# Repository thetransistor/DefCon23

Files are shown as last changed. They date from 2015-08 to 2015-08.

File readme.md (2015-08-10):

# DC801 2015 Defcon VIP Party Badge
[DC801](https://dc801.org/) and [theTransistor](http://thetransistor.com/) bring you yet another fun party badge.

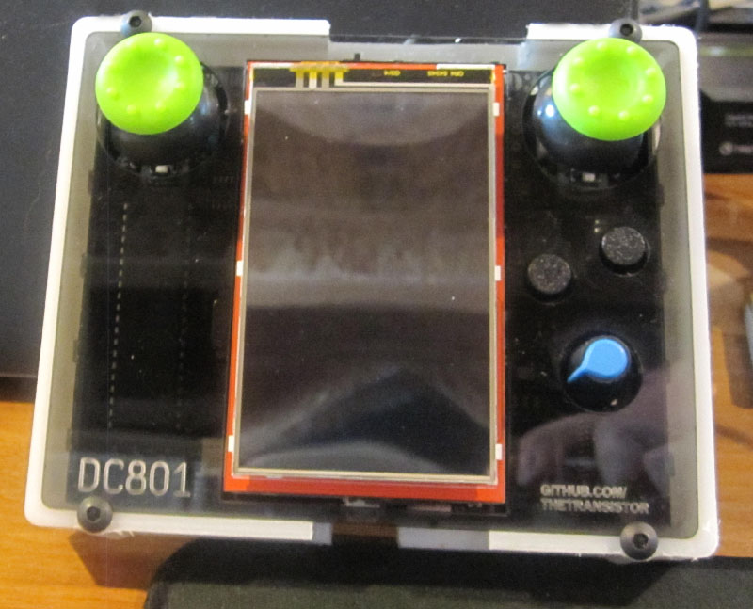
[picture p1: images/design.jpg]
Defcon VIP Party Badge 2015


##Features
- [Parallax Propeller mCU](https://www.parallax.com/product/p8x32a-d40)
- Atmega328P mCU (For analog and additional IO)
- ESP8266 (ESP-12E) WiFi Module
- Socket for XBee Serial Radio
- FTDI with Selectable Output via Bus Switch
- 3.6" LCD
  - 400x240 Resolution
  - 18-bit Color
  - ~~ILI9327~~ R61509V Chipset
- 2000 mAh LiPo Battery and Charging Circuit
- Awesome HDPE / Acrylic Case
- 2x Analog Joysticks
- Rotary Encoder
- 2x Pushbuttons
- 10x WS2812B RGB LED Pixels
- Charge / Voltage Readout Capabilities
- microSD Card

##Credits:

**Electronics Engineering**
- Compukidmike

**Original Design**
- D3c4f

**Case Manufacturing**
- [Isaac @ Rusted Friend](http://rustedfriend.com/)

**QA, Assembly, Software, Loading, Misc**
- @d3c4f
- @compukidmike
- @animcogn
- @aarobc (l3mur)
- @doktorunicorn
- @programm3rq
- @mindjuju
- @devil_bunny (yukaia)
- @nemus801
- SausageAssassn 

**Special Thanks**
- All you amazing hackers that help fund this project every year! <3
- DC801 and theTransistor Crews
- Utah Open Source

##Questions and Comments
Questions and comments can be directed towards the following forms of communication:
- #thetransistor on freenode
- d3c4f [at] thetransistor [dot] com

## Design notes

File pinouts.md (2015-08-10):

# DC801 2015 Pinout
Pinouts for the DC801 Electronic VIP Party Badge for Defcon 2015 for kids who can't read good and wanna learn to do other stuff good too

##Propeller IO Pinout
Propeller IO | LCD Pin
-------------|--------------
P0  | D2
P1  | D3
P2  | D4
P3  | D5
P4  | D6
P5  | D7
P6  | D0
P7  | D1
P11 | RST
P12 | CS
P13 | RS
P14 | RW
P15 | RD

Propeller IO | SD Card
-------------|--------------
P20 | SCK
P21 | DO
P22 | DI
P23 | SS

Propeller IO | RGB LEDS
-------------|--------------
P26 | Data

Propeller IO | XBee Socket
-------------|--------------
P8  | DOUT
P9  | DIN
P10 | RST

Propeller IO | WiFi
-------------|--------------
P24 | RX
P25 | TX
P27 | RST

Propeller IO | EEPROM
-------------|--------------
P28 | SCL
P29 | SDA

Propeller IO | PROP Serial
-------------|--------------
P30 | TX
P31 | RX

Propeller IO | Atmega 328P Arduino
-------------|--------------
P16 | D13 (SCK)
P17 | D12 (MISO)
P18 | D11 (MOSI)
P19 | D10 (CS)

##Atmega328P IO Pinout
328P | Arduino IO | Rotary Encoder
-----|------------|--------------
32 | D2 | Encoder 1
1  | D3 | Encoder 2

328P | Arduino IO | Buttons
-----|------------|--------------
2  | D4 | Button A
9  | D5 | Button B
10 | D6 | RightJoy Button
11 | D7 | LeftJoy Button

328P | Arduino IO | Joystick 
-----|------------|--------------
23 | A0 | LeftJoy X-Axis
24 | A1 | LeftJoy Y-Axis
25 | A2 | RightJoy X-Axis
26 | A3 | RightJoy Y-Axis

328P | Arduino IO | Propeller Link
-----|------------|--------------
14 | D10 | P19 (CS)
15 | D11 | P18 (MOSI)
16 | D12 | P17 (MISO)
17 | D13 | P16 (SCK)

328P | Arduino IO | Misc
-----|------------|--------------
27 | A4 | LCD Backlight Control
12 | D8 | Battery Stat 1
13 | D9 | Battery Stat 2
22 | A7 | Battery Voltage
30 | RX | Arduino RX
31 | TX | Arduino TX

328P | Arduino IO | Extra IO
-----|------------|--------------
19 | A6 | Extra IO 1
28 | A5 | Extra IO 2

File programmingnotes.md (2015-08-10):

# Programming notes
[DC801](https://dc801.org/) and [theTransistor](http://thetransistor.com/) bring you yet another fun party badge.

##Progamming the Propeller
- [Parallax Propeller mCU](https://www.parallax.com/product/p8x32a-d40)
- 1) Plug in your USB and slide the bottom switch to the left to select the Propeller Chip
- 2) Use your favorite Propeller Tool to program the chip.
NOTE: Make sure you have selected "RTS" as the Propeller Reset Signal (see image below)
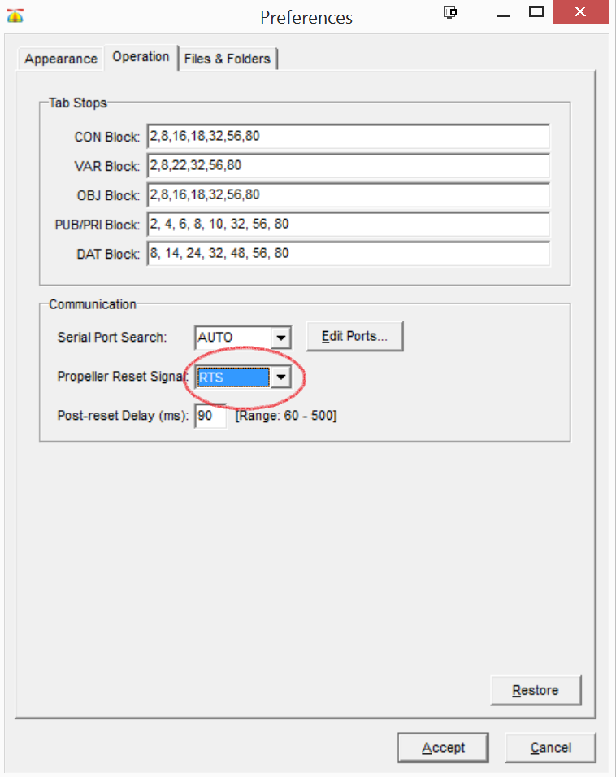
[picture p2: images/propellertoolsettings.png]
Defcon VIP Party Badge 2015


##Programing the Atmega328 Arduino
The Atmel 328P comes preloaded with the Arduino Bootloader. It sets up an SPI communication link between some of the IO (like the analog sticks) and the Propeller.
- 1) Plug in your USB and slide the bottom switch to the right to select the 328P
- 2) Use your favorite Arduino Programming Tool to program the chip.

##Flashing the Arduino Bootloader / Direct Atmel Programming
This is a little more advanced, and requires you to remove the Propeller chip from its socket. Please review the schematics if you wish to program the 329P directly.

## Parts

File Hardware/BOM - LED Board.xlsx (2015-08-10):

DC801 DEFCON23 Badge LED Board 2015
Qty | Value | Device | Package | Description
5 |  | WS2812B | WS2812B | WS2812B - Intelligent control LED integrated light source
5 | 0.1uF | C-USC0603 | C0603 | CAPACITOR, American symbol

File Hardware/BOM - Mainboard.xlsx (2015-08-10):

DC801 DEFCON23 Badge BOM 2015
Qty | Value | Device | Package | Description
1 |  | ENCODER-QUADRATURE | ENCODER-12MM-VERT | quadrature encoder EVE-GA1F2024B
1 | 1uH | INDUCTOR0805 | 805 | Inductors
1 |  | JST_2MM_MALE | JST-2-SMD | Mates to single-cell LiPo batteries.
1 | RED | LED0603 | LED-0603 | LED RED
3 | GRN | LED0603 | LED-0603 | LED GREEN
4 | 0.1uF | C-USC0805 | C0805 | CAPACITOR, American symbol
12 | 10K | R-US_R0603 | R0603 | RESISTOR, American symbol
1 | 10R | R-US_R0603 | R0603 | RESISTOR, American symbol
1 | 10uF | C-USC1206K | C1206K | CAPACITOR, American symbol
2 | 1uF | C-USC1206K | C1206K | CAPACITOR, American symbol
1 | 2.2uF | CAP0402-CAP | 0402-CAP | Capacitor
1 | 20K | R-US_R0603 | R0603 | RESISTOR, American symbol
1 | 2K | R-US_R0603 | R0603 | RESISTOR, American symbol
2 | 4.7uF | CAP0603-CAP | 0603-CAP | Capacitor
4 | 360R | R-US_R0603 | R0603 | RESISTOR, American symbol
1 | 5MHz | CRYSTAL-TH-11.5X5MM | CRYSTAL-SMD | Crystal 5MHz
1 | CBT3244AD | CBT3244AD | SO20W | Octal BUS Switch
1 | 8MHZ | RESONATOR-AWSCR | RESONATOR-AWSCR-CV | Resonator
1 | ARDUINO_SHIELD3.5LCD | ARDUINO_SHIELD3.5LCD | 3.6TFT-LCD-SHIELD | 3.6" TFT LCD Arduino shield
2 | 8PosHeader | 8PosHeader | 8Pos | 8 Position Headers for Arduino Shield LCD
2 | 6PosHeader | 6PosHeader | 6Pos | 6 Position Headers for Arduino Shield LCD
1 | ATMEGA328P | ATMEGA328_SMT | TQFP32-08 | 32-Pin Atmega328 part
1 | FDT434P | FDT434P | SOT223 | MOSFET P-Ch
1 | EEPROM-I2CSMD | EEPROM-I2CSMD | SO08 | I2C EEPROM chip, 24LC256
1 | ESP8266_ESP-12 | ESP8266_ESP-12 | ESP8266-ESP12 | ESP8266 ESP-12 WiFi Module
1 | FAN4860 | FAN4860 | 6-UMLP | Step-Up Boost Converter 5V
1 | FT232RLSSOP | FT232RLSSOP | SSOP28DB | USB UART FT232RL
1 | JOYSTICKPTH-LEFT | JOYSTICKPTH | JOYSTICK | Thumb Joystick
1 | JOYSTICKPTH-RIGHT | JOYSTICKPTH | JOYSTICK | Thumb Joystick
2 | Joystick Cap | Joystick Cap | Joystick Cap | Thumb Joystick Caps
2 | JS102011SAQN | JS102011SAQN | SAQN | CK-Components
1 | MCP73834 | MCP73834 | MSOP-10 | Stand-alone Linear Li-ion/Li-polymer Charge Management Controller
1 | MYCON2_USB-MINI-B | MYCON2_USB-MINI-B | CON2_USB_MICRO_B_AT | Micro USB B Connector
1 | P8X32A-D40 (Socket Only) | P8X32A-D40 (Socket Only) | DIP-40 | Parallax Propeller P8X32A-D40
2 | SWITCH-MOMENTARY-2PTH-LARGE | SWITCH-MOMENTARY-2PTH-LARGE | TACTILE-PTH-LARGE | Pushbutton
1 | V_REG_AP2114H-3.3 | V_REG_AP2114 | SOT223 | 3.3V LDO Regulator
2 | XBEE-1B2 (Header Only) | XBEE-1B2 (Header Only) | XBEE-SILK | Xbee module footprints

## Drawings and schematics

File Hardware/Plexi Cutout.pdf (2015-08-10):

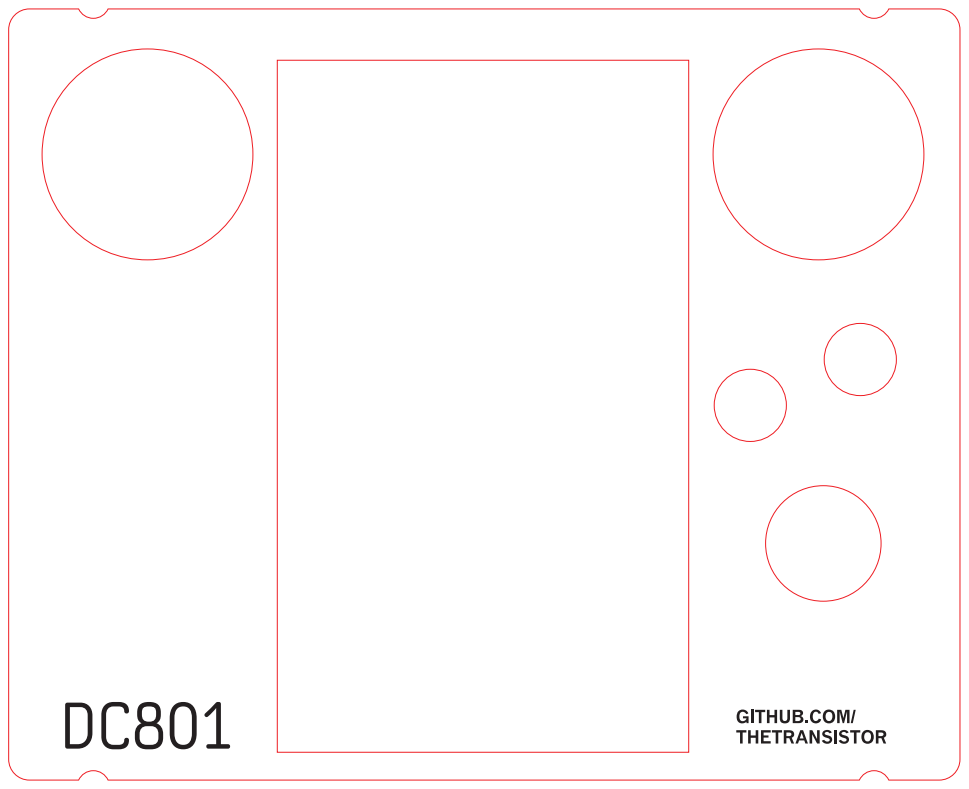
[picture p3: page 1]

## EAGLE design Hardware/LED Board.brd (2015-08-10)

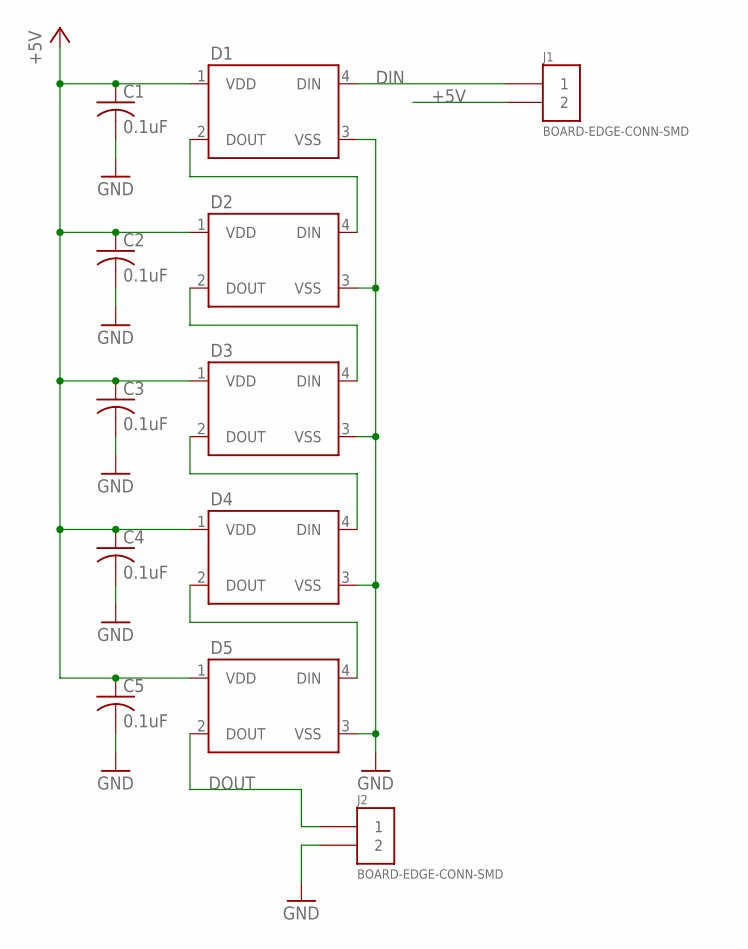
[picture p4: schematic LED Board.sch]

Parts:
C1, C2, C3, C4, C5: 0.1uF; C0603
D1, D2, D3, D4, D5: WS2812B
J1, J2: BOARD-EDGE-CONN-SMD; SMD-2

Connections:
+5V: C1.1, C2.1, C3.1, C4.1, C5.1, D1.1 (VDD), D2.1 (VDD), D3.1 (VDD), D4.1 (VDD), D5.1 (VDD), J1.P$2 (2)
DIN: D1.4 (DIN), J1.P$1 (1)
DOUT: D5.2 (DOUT), J2.P$1 (1)
GND: C1.2, C2.2, C3.2, C4.2, C5.2, D1.3 (VSS), D2.3 (VSS), D3.3 (VSS), D4.3 (VSS), D5.3 (VSS), J2.P$2 (2)
unnamed: D1.2 (DOUT), D2.4 (DIN)
unnamed: D2.2 (DOUT), D3.4 (DIN)
unnamed: D3.2 (DOUT), D4.4 (DIN)
unnamed: D4.2 (DOUT), D5.4 (DIN)

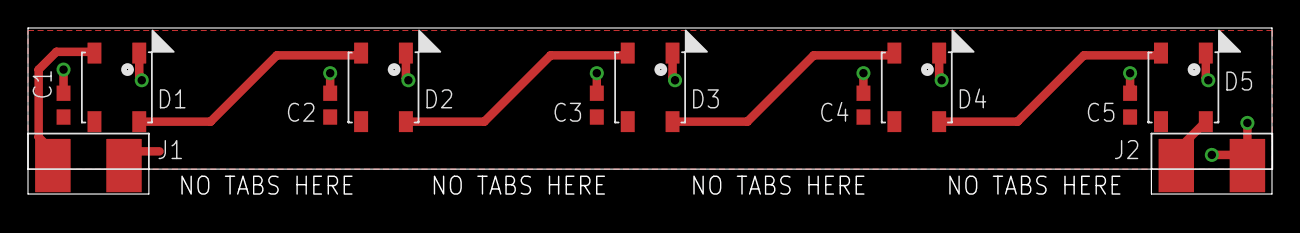
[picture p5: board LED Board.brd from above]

Board: 2 copper layers, 88.9 x 11.9 mm, 12 parts (0 on the bottom side), 8 nets.

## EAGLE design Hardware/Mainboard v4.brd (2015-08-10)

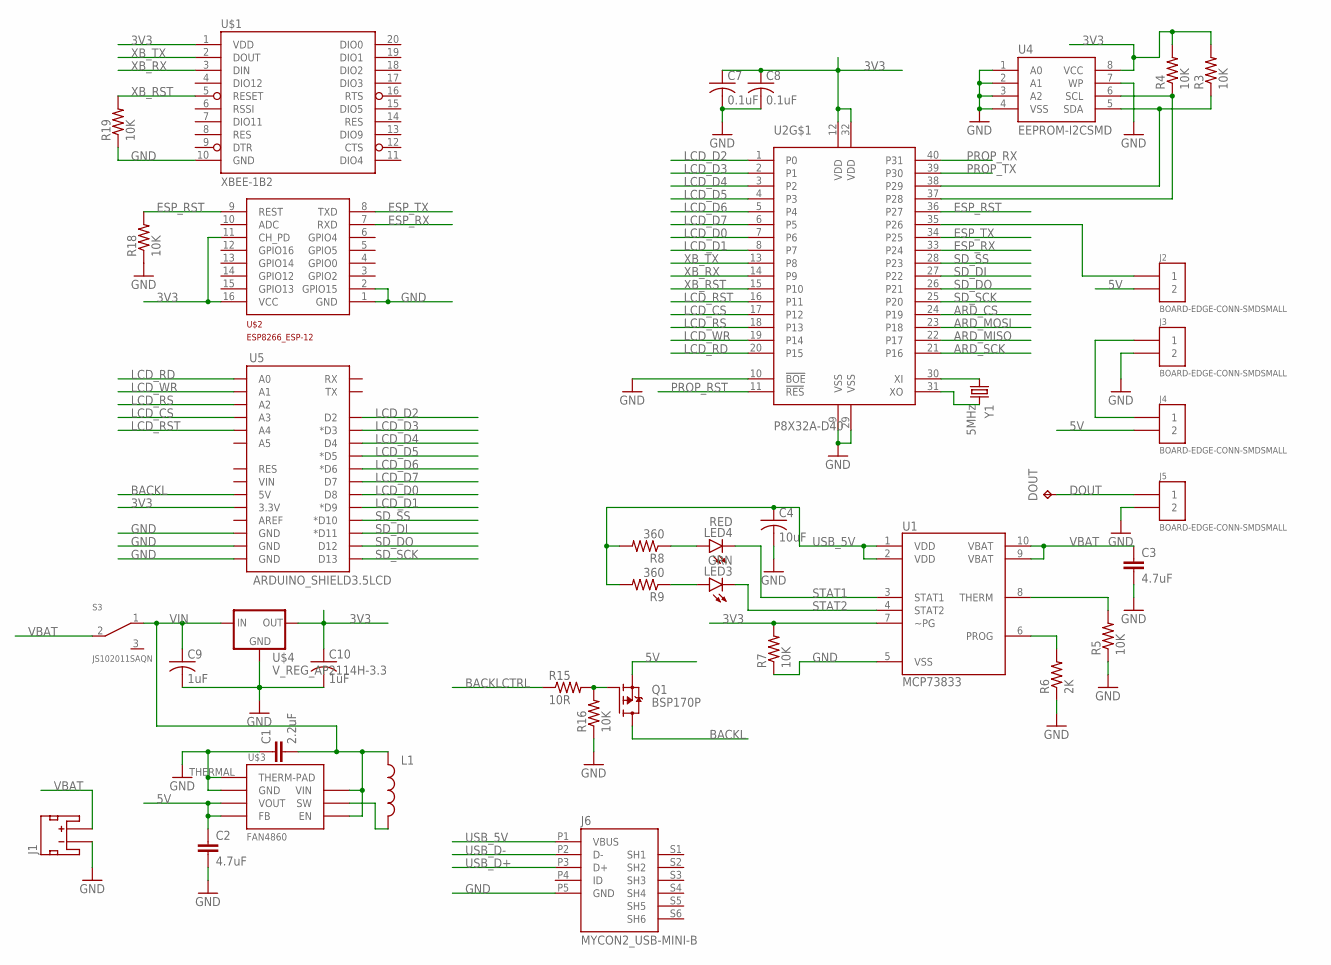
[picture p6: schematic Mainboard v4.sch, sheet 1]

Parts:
C1: 2.2uF; 0402-CAP
C2, C3: 4.7uF; 0603-CAP
C4: 10uF; C1206K
C7, C8: 0.1uF; C0805
C9, C10: 1uF; C1206K
DOUT: TPPAD1-13; P1-13
J1: JST_2MM_MALE; JST-2-SMD
J2, J3, J4, J5: BOARD-EDGE-CONN-SMDSMALL; SMD-2-SMALL
J6: MYCON2_USB-MINI-B; CON2_USB_MICRO_B_AT
L1: INDUCTOR0805; 0805
LED3: GRN; LED-0603
LED4: RED; LED-0603
Q1: BSP170P; SOT223
R3, R4, R5, R7, R16, R18, R19: 10K; R0603
R6: 2K; R0603
R8, R9: 360; R0603
R15: 10R; R0603
S3: JS102011SAQN; SAQN
U1: MCP73833; MSOP-10
U2: P8X32A-D40; DIP-40
U4: EEPROM-I2CSMD; SO08
U5: ARDUINO_SHIELD3.5LCD; 3.6TFT-LCD-SHIELD
U$1: XBEE-1B2; XBEE-SILK
U$2: ESP8266_ESP-12; ESP8266-ESP12E
U$3: FAN4860; 6-UMLP
U$4: V_REG_AP2114H-3.3; SOT223
Y1: 5MHz; CRYSTAL-SMD

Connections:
3V3: C7.1, C8.1, C10.1, R3.2, R4.2, R7.2, U1.7 (~PG), U2.12 (VDD), U2.32 (VDD), U4.8 (VCC), U5.3.3V, U$1.1 (VDD), U$2.11 (CH_PD), U$2.16 (VCC), U$4.2 (OUT); also elsewhere on the board
5V: C2.1, J2.P$2 (2), J4.P$2 (2), Q1.3 (S), U$3.P$2 (VOUT), U$3.P$3 (FB)
ARD_CS: U2.24 (P19); also elsewhere on the board
ARD_MISO: U2.22 (P17); also elsewhere on the board
ARD_MOSI: U2.23 (P18); also elsewhere on the board
ARD_SCK: U2.21 (P16); also elsewhere on the board
BACKL: Q1.2 (D), Q1.4 (D), U5.5V
BACKLCTRL: R15.1; also elsewhere on the board
DOUT: DOUT.TP, J5.P$1 (1)
ESP_RST: R18.2, U2.36 (P27), U$2.9 (REST)
ESP_RX: U2.33 (P24), U$2.7 (RXD)
ESP_TX: U2.34 (P25), U$2.8 (TXD)
GND: C1.1, C2.2, C3.2, C4.2, C7.2, C8.2, C9.2, C10.2, J1.1 (-), J3.P$2 (2), J5.P$2 (2), J6.P5 (GND), R5.1, R6.1, R7.1, R16.1, R18.1, R19.1, U1.5 (VSS), U2.9 (VSS), U2.10 (!BOE), U2.29 (VSS), U4.1 (A0), U4.2 (A1), U4.3 (A2), U4.4 (VSS), U4.7 (WP), U5.GND@0 (GND), U5.GND@1 (GND), U5.GND@2 (GND), U$1.10 (GND), U$2.1 (GND), U$2.2 (GPIO15), U$3.P$1 (GND), U$3.THERMAL (THERM-PAD), U$4.1 (GND); also elsewhere on the board
LCD_CS: U2.17 (P12), U5.A3
LCD_D0: U2.7 (P6), U5.D8
LCD_D1: U2.8 (P7), U5.D9 (*D9)
LCD_D2: U2.1 (P0), U5.D2
LCD_D3: U2.2 (P1), U5.D3 (*D3)
LCD_D4: U2.3 (P2), U5.D4
LCD_D5: U2.4 (P3), U5.D5 (*D5)
LCD_D6: U2.5 (P4), U5.D6 (*D6)
LCD_D7: U2.6 (P5), U5.D7
LCD_RD: U2.20 (P15), U5.A0
LCD_RS: U2.18 (P13), U5.A2
LCD_RST: U2.16 (P11), U5.A4
LCD_WR: U2.19 (P14), U5.A1
unnamed: J3.P$1 (1), J4.P$1 (1)
unnamed: J2.P$1 (1), U2.35 (P26)
unnamed: R4.1, U2.37 (P28), U4.6 (SCL)
unnamed: R3.1, U2.38 (P29), U4.5 (SDA)
unnamed: U2.30 (XI), Y1.P$1 (1)
unnamed: U2.31 (XO), Y1.P$2 (2)
unnamed: LED4.A, R8.1
unnamed: LED3.A, R9.1
unnamed: R5.2, U1.8 (THERM)
unnamed: Q1.1 (G), R15.2, R16.2
unnamed: R6.2, U1.6 (PROG)
unnamed: L1.2, U$3.P$5 (SW)
PROP_RST: U2.11 (!RES)
PROP_RX: U2.40 (P31); also elsewhere on the board
PROP_TX: U2.39 (P30); also elsewhere on the board
SD_DI: U2.27 (P22), U5.D11 (*D11)
SD_DO: U2.26 (P21), U5.D12
SD_SCK: U2.25 (P20), U5.D13
SD_SS: U2.28 (P23), U5.D10 (*D10)
STAT1: LED4.C, U1.3 (STAT1); also elsewhere on the board
STAT2: LED3.C, U1.4 (STAT2); also elsewhere on the board
USB_5V: C4.1, J6.P1 (VBUS), R8.2, R9.2, U1.1 (VDD), U1.2 (VDD); also elsewhere on the board
USB_D+: J6.P3 (D+); also elsewhere on the board
USB_D-: J6.P2 (D-); also elsewhere on the board
VBAT: C3.1, J1.2 (+), S3.2, U1.9 (VBAT), U1.10 (VBAT); also elsewhere on the board
VIN: C1.2, C9.1, L1.1, S3.1, U$3.P$4 (EN), U$3.P$6 (VIN), U$4.3 (IN)
XB_RST: R19.2, U2.15 (P10), U$1.5 (RESET)
XB_RX: U2.14 (P9), U$1.3 (DIN)
XB_TX: U2.13 (P8), U$1.2 (DOUT)

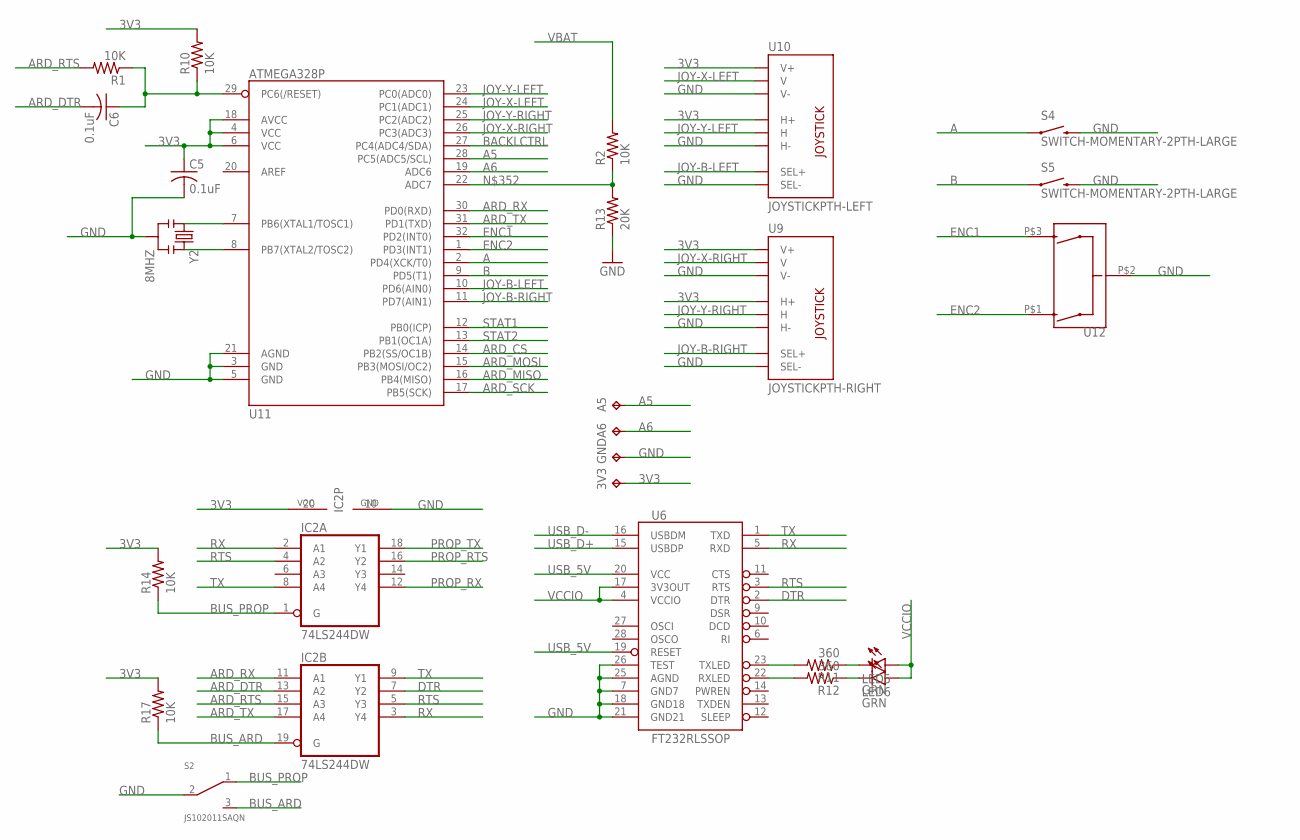
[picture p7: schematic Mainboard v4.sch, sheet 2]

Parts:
3V3: TPPAD1-13; P1-13
A5, A6: TPPAD1-13; P1-13
C5, C6: 0.1uF; C0805
GND: TPPAD1-13; P1-13
IC2: 74LS244DW; SO20W
LED5, LED6: GRN; LED-0603
R1, R2, R10, R14, R17: 10K; R0603
R11, R12: 360; R0603
R13: 20K; R0603
S2: JS102011SAQN; SAQN
S4, S5: SWITCH-MOMENTARY-2PTH-LARGE; TACTILE-PTH-LARGE
U6: FT232RLSSOP; SSOP28DB
U9: JOYSTICKPTH-RIGHT; JOYSTICK
U10: JOYSTICKPTH-LEFT; JOYSTICK
U11: ATMEGA328P; TQFP32-08
U12: ENCODER-QUADRATURE; ENCODER-12MM-VERT-SQ
Y2: 8MHZ; RESONATOR-AWSCR-CV

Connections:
3V3: 3V3.TP, C5.1, IC2.20 (VCC), R10.2, R14.2, R17.2, U9.H1 (H+), U9.V1 (V+), U10.H1 (H+), U10.V1 (V+), U11.4 (VCC), U11.6 (VCC), U11.18 (AVCC); also elsewhere on the board
A: S4.P$1 (1), U11.2 (PD4(XCK/T0))
A5: A5.TP, U11.28 (PC5(ADC5/SCL))
A6: A6.TP, U11.19 (ADC6)
ARD_CS: U11.14 (PB2(SS/OC1B)); also elsewhere on the board
ARD_DTR: C6.2, IC2.13 (A2)
ARD_MISO: U11.16 (PB4(MISO)); also elsewhere on the board
ARD_MOSI: U11.15 (PB3(MOSI/OC2)); also elsewhere on the board
ARD_RTS: IC2.15 (A3), R1.2
ARD_RX: IC2.11 (A1), U11.30 (PD0(RXD))
ARD_SCK: U11.17 (PB5(SCK)); also elsewhere on the board
ARD_TX: IC2.17 (A4), U11.31 (PD1(TXD))
B: S5.P$1 (1), U11.9 (PD5(T1))
BACKLCTRL: U11.27 (PC4(ADC4/SDA)); also elsewhere on the board
BUS_ARD: IC2.19 (G), R17.1, S2.3
BUS_PROP: IC2.1 (G), R14.1, S2.1
DTR: IC2.7 (Y2), U6.2 (DTR)
ENC1: U11.32 (PD2(INT0)), U12.P$3 (B)
ENC2: U11.1 (PD3(INT1)), U12.P$1 (A)
GND: C5.2, GND.TP, IC2.10 (GND), R13.1, S2.2, S4.P$2 (2), S5.P$2 (2), U6.7 (GND7), U6.18 (GND18), U6.21 (GND21), U6.25 (AGND), U6.26 (TEST), U9.B2A (SEL-), U9.H3 (H-), U9.V3 (V-), U10.B2A (SEL-), U10.H3 (H-), U10.V3 (V-), U11.3 (GND), U11.5 (GND), U11.21 (AGND), U12.P$2 (C), Y2.P$2 (2); also elsewhere on the board
JOY-B-LEFT: U10.B1A (SEL+), U11.10 (PD6(AIN0))
JOY-B-RIGHT: U9.B1A (SEL+), U11.11 (PD7(AIN1))
JOY-X-LEFT: U10.V2 (V), U11.24 (PC1(ADC1))
JOY-X-RIGHT: U9.V2 (V), U11.26 (PC3(ADC3))
JOY-Y-LEFT: U10.H2 (H), U11.23 (PC0(ADC0))
JOY-Y-RIGHT: U9.H2 (H), U11.25 (PC2(ADC2))
unnamed: R11.2, U6.23 (TXLED)
unnamed: R12.2, U6.22 (RXLED)
unnamed: LED5.C, R11.1
unnamed: LED6.C, R12.1
unnamed: U11.7 (PB6(XTAL1/TOSC1)), Y2.P$1 (1)
unnamed: U11.8 (PB7(XTAL2/TOSC2)), Y2.P$3 (3)
unnamed: C6.1, R1.1, R10.1, U11.29 (PC6(/RESET))
unnamed: R2.1, R13.2, U11.22 (ADC7)
PROP_RTS: IC2.16 (Y2)
PROP_RX: IC2.12 (Y4); also elsewhere on the board
PROP_TX: IC2.18 (Y1); also elsewhere on the board
RTS: IC2.4 (A2), IC2.5 (Y3), U6.3 (RTS)
RX: IC2.2 (A1), IC2.3 (Y4), U6.5 (RXD)
STAT1: U11.12 (PB0(ICP)); also elsewhere on the board
STAT2: U11.13 (PB1(OC1A)); also elsewhere on the board
TX: IC2.8 (A4), IC2.9 (Y1), U6.1 (TXD)
USB_5V: U6.19 (RESET), U6.20 (VCC); also elsewhere on the board
USB_D+: U6.15 (USBDP); also elsewhere on the board
USB_D-: U6.16 (USBDM); also elsewhere on the board
VBAT: R2.2; also elsewhere on the board
VCCIO: LED5.A, LED6.A, U6.4 (VCCIO), U6.17 (3V3OUT)

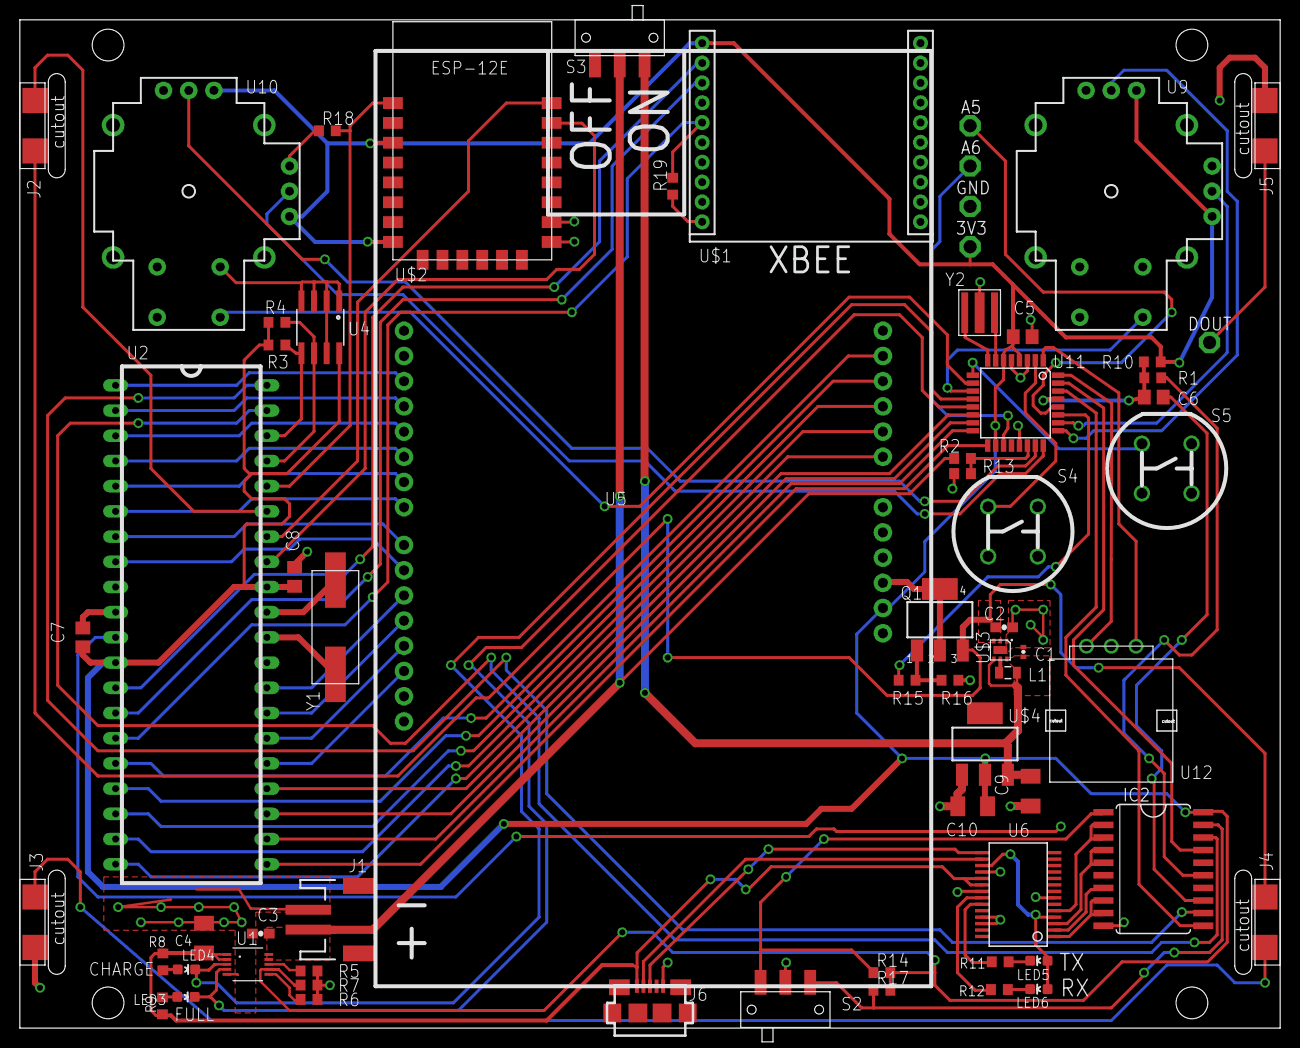
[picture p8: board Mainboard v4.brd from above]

Board: 5 copper layers, 127.0 x 101.6 mm, 66 parts (0 on the bottom side), 85 nets.

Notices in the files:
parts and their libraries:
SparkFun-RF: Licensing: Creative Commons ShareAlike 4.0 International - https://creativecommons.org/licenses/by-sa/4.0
